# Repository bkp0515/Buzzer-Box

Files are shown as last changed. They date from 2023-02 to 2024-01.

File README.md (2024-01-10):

# Buzzer-Box
A project designed to create an alternative solution to existing buzzer systems for bible quizzing.

## Features
The hardware revision 2 contains new features like a larger buzzer with hardware controllable volume courtousy of a PAM8904.
Additionally, the faceplate has been redesigned to operate on i2c communication to be removable with just a single 5 pin JST connection.
Being based on the ESP32 feather V2 by adafruit, bluetooth and wifi features will be added eventually. 
Build guide and BOM to come after prototyping hardware V2 is more solidified.

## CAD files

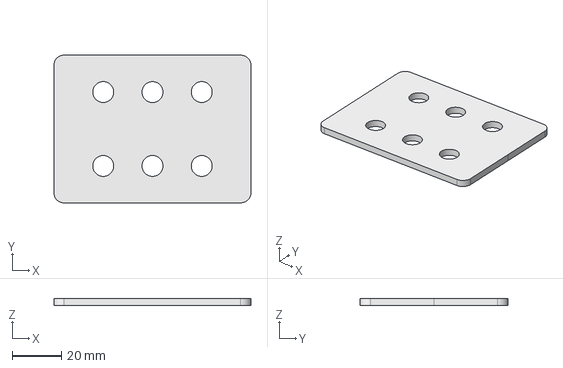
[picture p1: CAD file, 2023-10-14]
3dModels/QuizBoxMk2.FCStd
80.0 x 60.0 x 3.00 mm

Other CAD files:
3dModels/QuizBoxMk2-Sketch001.stl

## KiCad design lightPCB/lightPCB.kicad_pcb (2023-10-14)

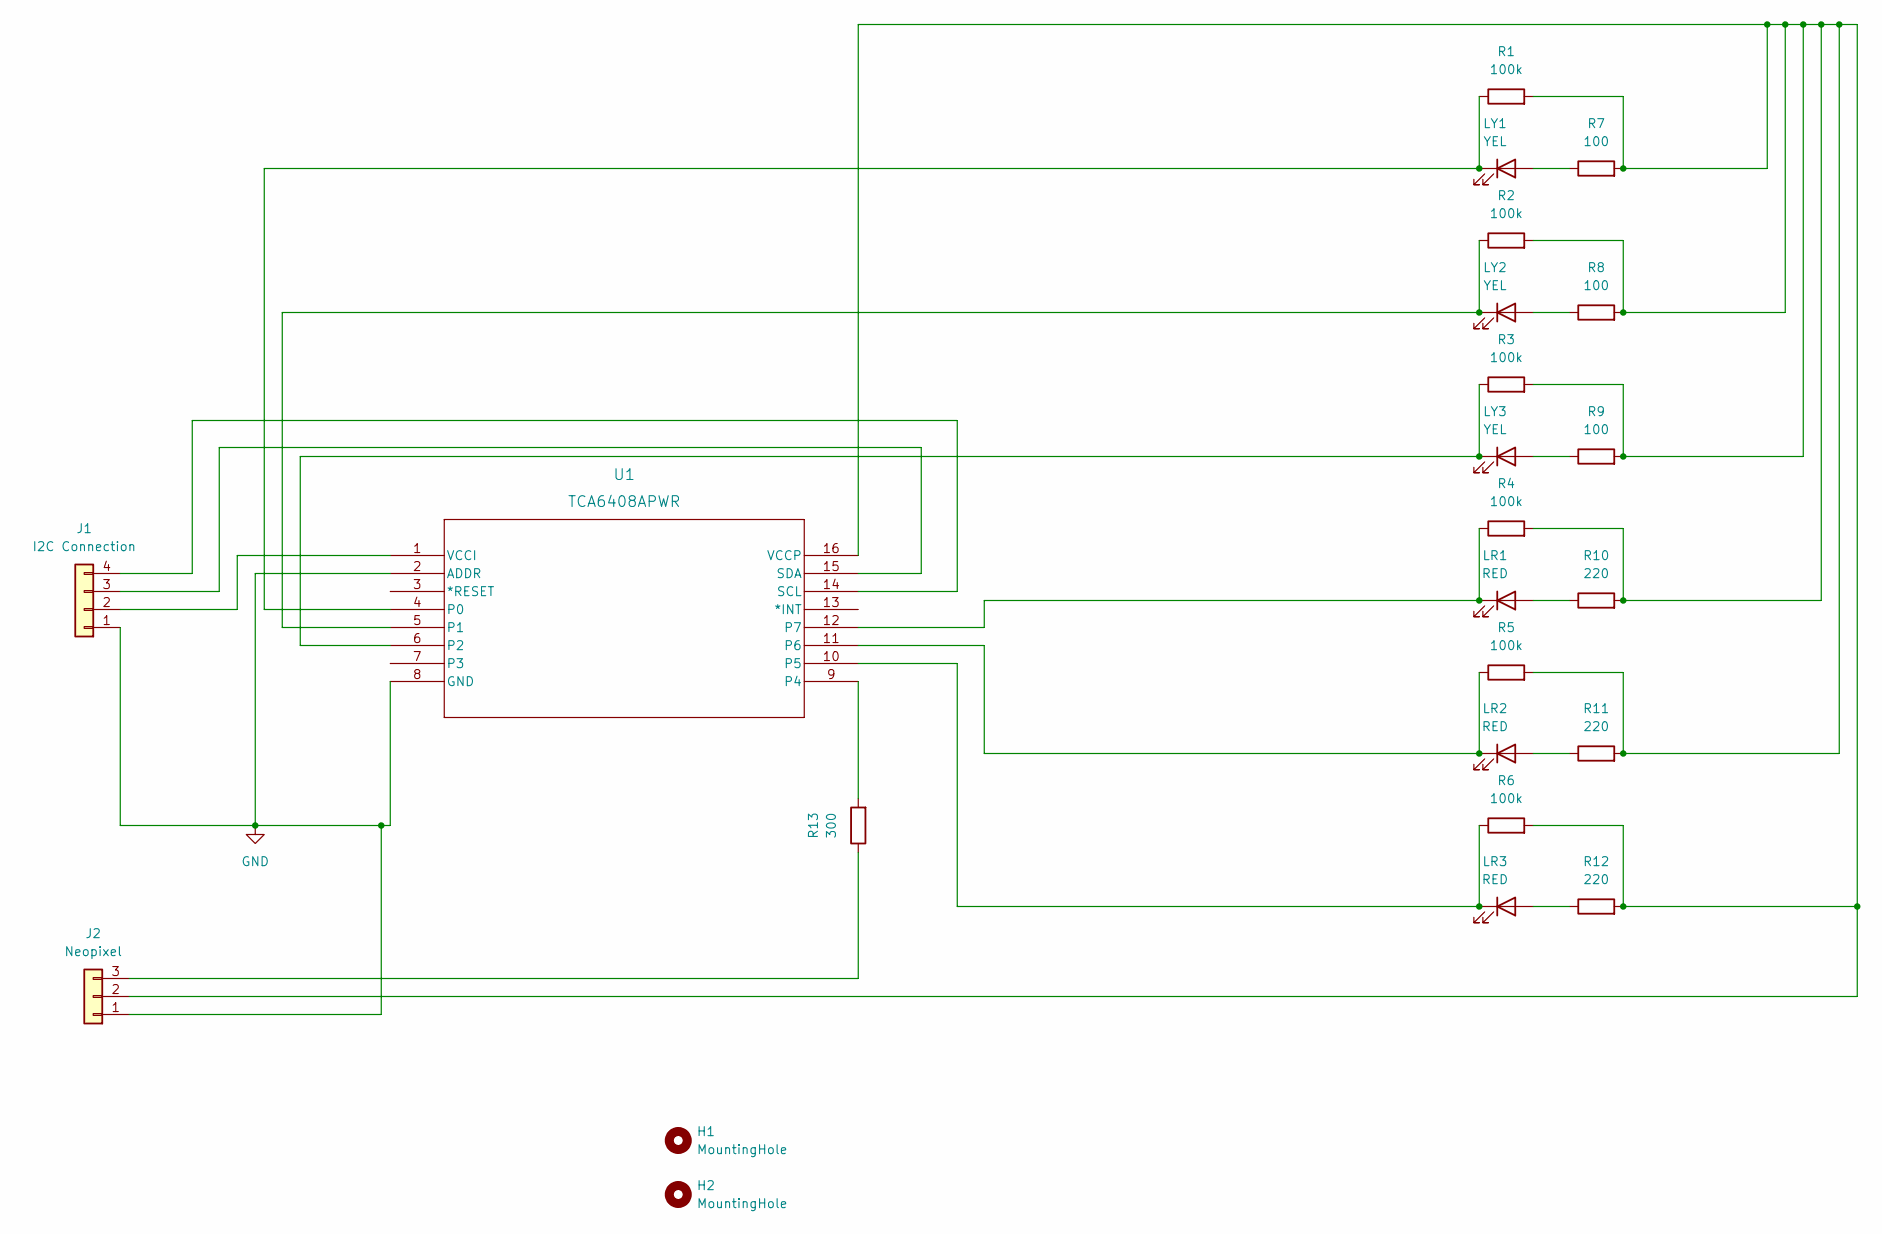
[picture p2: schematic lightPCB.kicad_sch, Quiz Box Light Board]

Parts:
H1, H2: MountingHole; MountingHole_2.2mm_M2_Pad
J1: I2C Connection; PinHeader_1x04_P2.54mm_Vertical
J2: Neopixel; PinHeader_1x03_P2.54mm_Vertical
LR1, LR2, LR3: RED; LED_D5.0mm
LY1, LY2, LY3: YEL; LED_D5.0mm
R1, R2, R3, R4, R5, R6: 100k; R_1206_3216Metric
R7, R8, R9: 100; R_1206_3216Metric
R10, R11, R12: 220; R_1206_3216Metric
R13: 300; R_1206_3216Metric
U1: TCA6408APWR; PW16

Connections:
GND: J1.1, J2.1, U1.2 (ADDR), U1.8 (GND)
unnamed: J1.2, U1.1 (VCCI)
unnamed: J2.3, R13.1
unnamed: LR1.2 (A), R10.1
unnamed: LR2.2 (A), R11.1
unnamed: LR3.2 (A), R12.1
unnamed: LY1.2 (A), R7.1
unnamed: LY2.2 (A), R8.1
unnamed: LY3.2 (A), R9.1
unnamed: LY1.1 (K), R1.1, U1.4 (P0)
unnamed: LY2.1 (K), R2.1, U1.5 (P1)
unnamed: LY3.1 (K), R3.1, U1.6 (P2)
unnamed: R13.2, U1.9 (P4)
unnamed: LR3.1 (K), R6.1, U1.10 (P5)
unnamed: LR2.1 (K), R5.1, U1.11 (P6)
unnamed: LR1.1 (K), R4.1, U1.12 (P7)
unnamed: J1.4, U1.14 (SCL)
unnamed: J1.3, U1.15 (SDA)
unnamed: J2.2, R1.2, R2.2, R3.2, R4.2, R5.2, R6.2, R7.2, R8.2, R9.2, R10.2, R11.2, R12.2, U1.16 (VCCP)

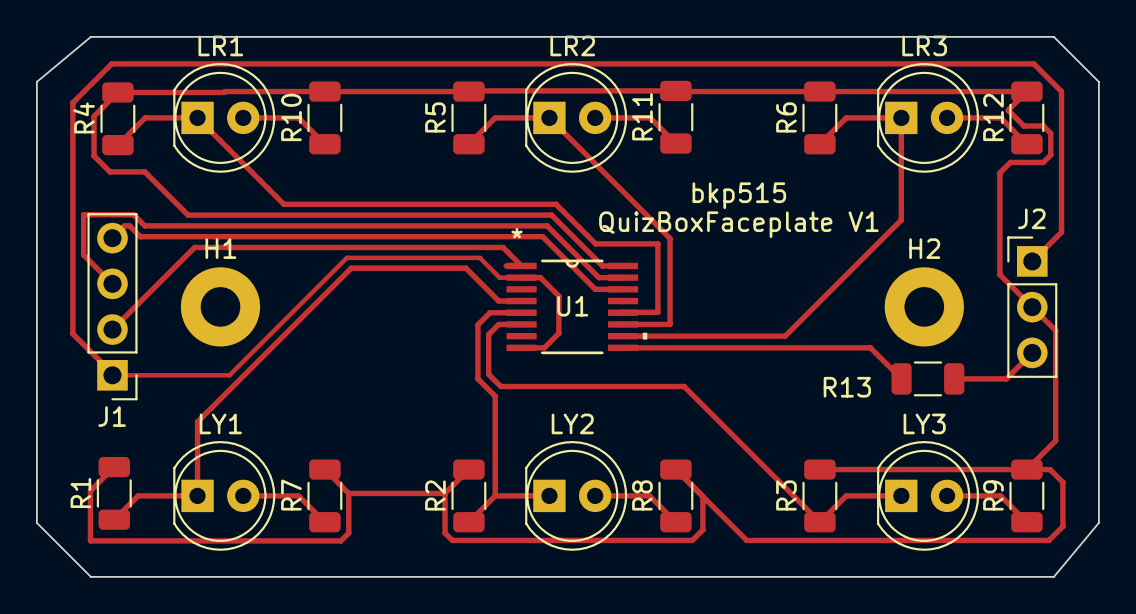
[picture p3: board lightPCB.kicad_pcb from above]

Board: 2 copper layers, 59.0 x 30.0 mm, 24 parts (0 on the bottom side), 19 nets.

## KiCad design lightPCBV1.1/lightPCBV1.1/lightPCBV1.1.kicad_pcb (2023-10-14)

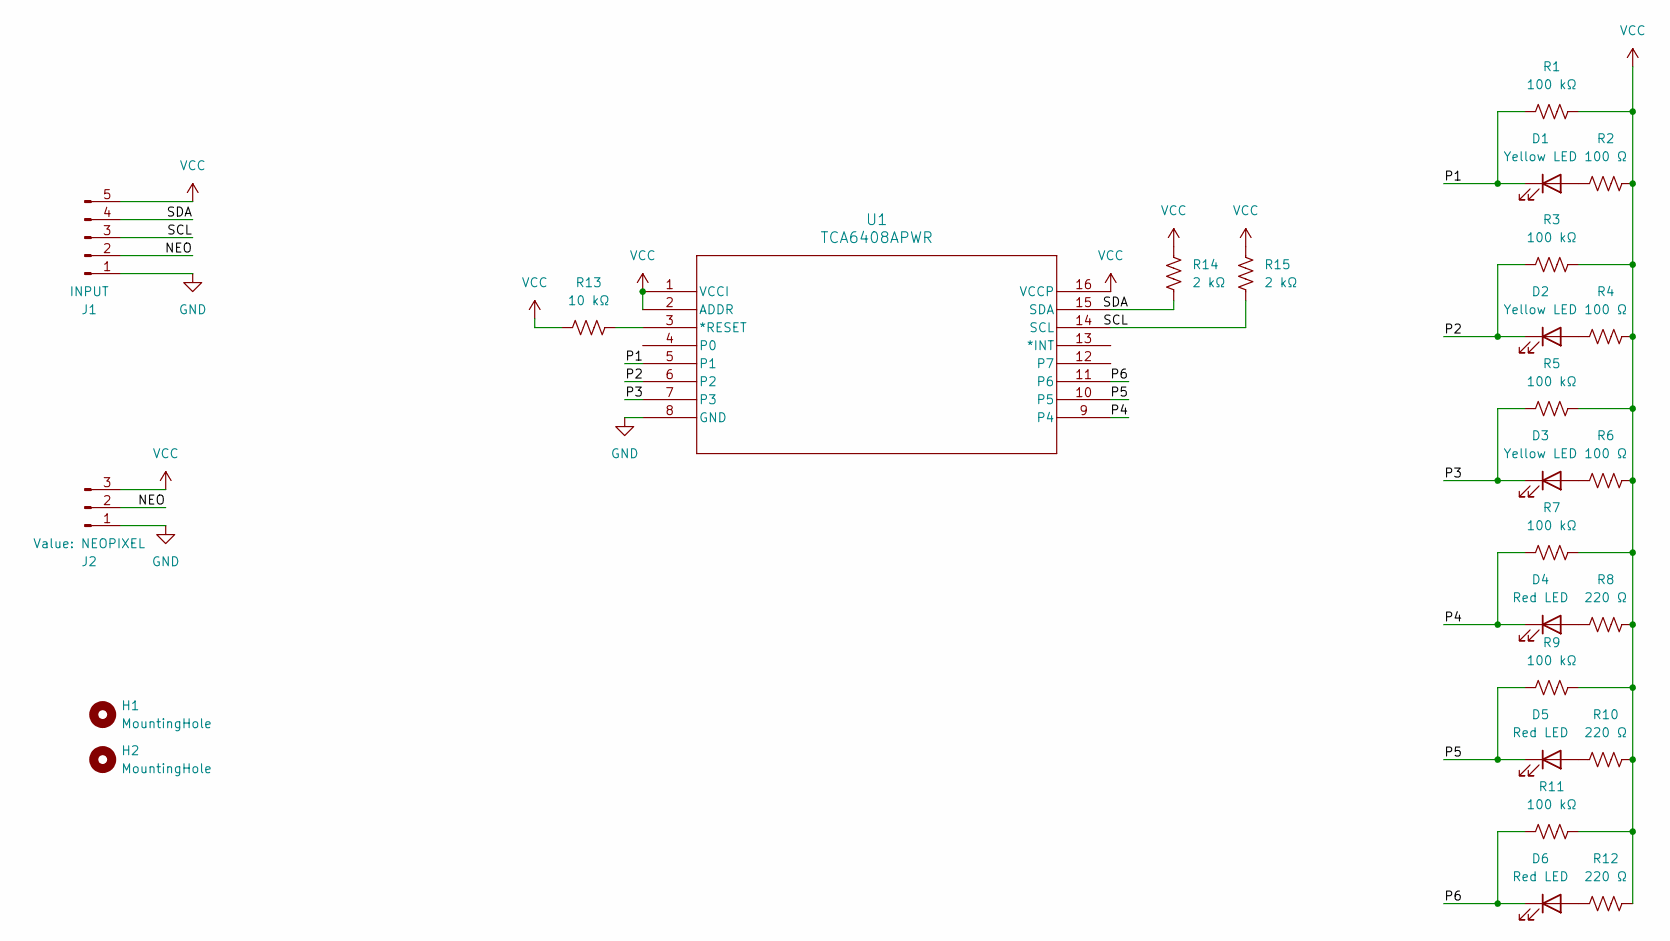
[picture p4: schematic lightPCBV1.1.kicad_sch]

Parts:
D1, D2, D3: Yellow LED; LED_D5.0mm
D4, D5, D6: Red LED; LED_D5.0mm
H1, H2: MountingHole; MountingHole_2.2mm_M2
J1: INPUT; JST_PH_B5B-PH-K_1x05_P2.00mm_Vertical
J2: NEOPIXEL; PinHeader_1x03_P2.54mm_Vertical
R1, R3, R5, R7, R9, R11: 100 kΩ; R_1206_3216Metric_Pad1.30x1.75mm_HandSolder
R2, R4, R6: 100 Ω; R_1206_3216Metric_Pad1.30x1.75mm_HandSolder
R8, R10, R12: 220 Ω; R_1206_3216Metric_Pad1.30x1.75mm_HandSolder
R13: 10 kΩ; R_1206_3216Metric_Pad1.30x1.75mm_HandSolder
R14, R15: 2 kΩ; R_1206_3216Metric_Pad1.30x1.75mm_HandSolder
U1: TCA6408APWR; PW16

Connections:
/NEO: J1.2, J2.2
/P1: D1.1 (K), R1.1, U1.5 (P1)
/P2: D2.1 (K), R3.1, U1.6 (P2)
/P3: D3.1 (K), R5.1, U1.7 (P3)
/P4: D4.1 (K), R7.1, U1.9 (P4)
/P5: D5.1 (K), R9.1, U1.10 (P5)
/P6: D6.1 (K), R11.1, U1.11 (P6)
/SCL: J1.3, R15.2, U1.14 (SCL)
/SDA: J1.4, R14.1, U1.15 (SDA)
GND: J1.1, J2.1, U1.8 (GND)
unnamed: D1.2 (A), R2.1
unnamed: D2.2 (A), R4.1
unnamed: D3.2 (A), R6.1
unnamed: D4.2 (A), R8.1
unnamed: D5.2 (A), R10.1
unnamed: D6.2 (A), R12.1
unnamed: R13.2, U1.3 (*RESET)
VCC: J1.5, J2.3, R1.2, R2.2, R3.2, R4.2, R5.2, R6.2, R7.2, R8.2, R9.2, R10.2, R11.2, R12.2, R13.1, R14.2, R15.1, U1.1 (VCCI), U1.2 (ADDR), U1.16 (VCCP)

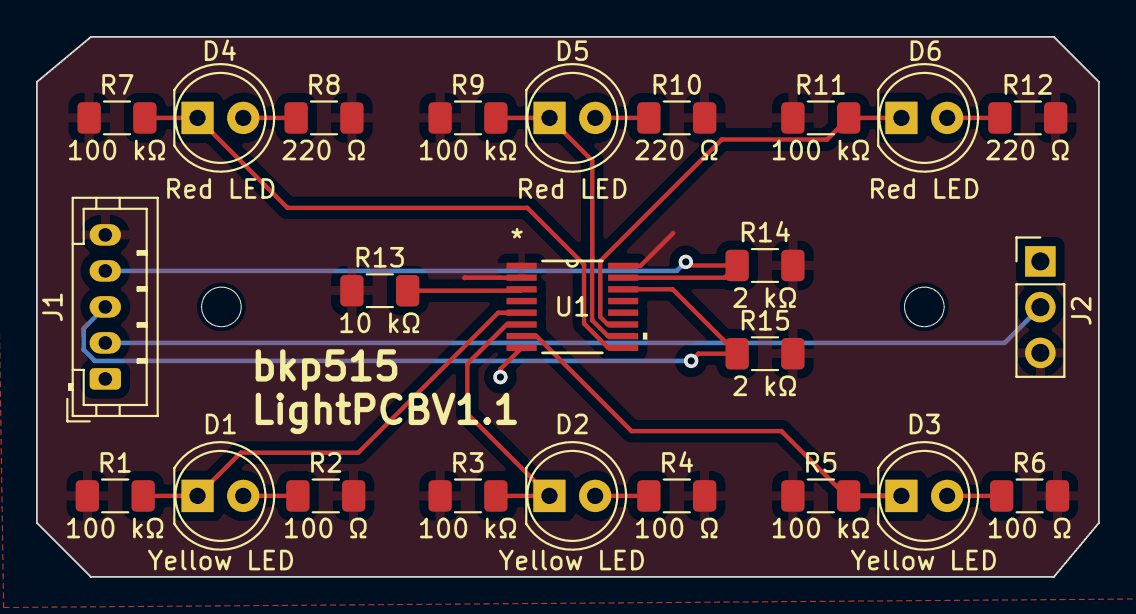
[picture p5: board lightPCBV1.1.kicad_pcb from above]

Board: 2 copper layers, 59.0 x 30.0 mm, 26 parts (0 on the bottom side), 18 nets.

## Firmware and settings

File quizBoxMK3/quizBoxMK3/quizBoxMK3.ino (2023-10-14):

// Quiz Box Mk. 3 Ben Pacheco 2/16/23
// Updated 2/21/23
////////////////////////////////////////////////////////////////////////////////////////////
// Library includes
#include <Adafruit_NeoPixel.h>
#include "driver/rtc_io.h"
#include <FastLED.h>
#ifdef __AVR__
#include <avr/power.h>
#endif

////////////////////////////////////////////////////////////////////////////////////////////
// Sleep function setup stuff
////////////////////////////////////////////////////////////////////////////////////////////

#define BUTTON_PIN_BITMASK 0x004000000 // 2^26 in hex define power switch pin
#define ps    26 // Power switch pin define

////////////////////////////////////////////////////////////////////////////////////////////
// End sleep function stuff
////////////////////////////////////////////////////////////////////////////////////////////


////////////////////////////////////////////////////////////////////////////////////////////
// Neopixel Setup Stuff
////////////////////////////////////////////////////////////////////////////////////////////

#define DATA_PIN    19 //Set pin for neopixels
#define NUM_LEDS    8  //Set number of neopixels

// Input the neopixel variables
CRGB leds[NUM_LEDS];
//Adafruit_NeoPixel pixels(NUMPIXELS, neoPIN, NEO_GRB + NEO_KHZ800);

////////////////////////////////////////////////////////////////////////////////////////////
// End Neopixel Setup
////////////////////////////////////////////////////////////////////////////////////////////


////////////////////////////////////////////////////////////////////////////////////////////
// Timer Setup
////////////////////////////////////////////////////////////////////////////////////////////
// Timer variables
volatile uint8_t isrCounter = 0;
volatile bool timerOn = false;
uint8_t pixelsOn = 0;

// Setup timer
hw_timer_t * timer = NULL;
hw_timer_t * speedTimer = NULL;
hw_timer_t * buzzTimer = NULL;

////////////////////////////////////////////////////////////////////////////////////////////
// End timer setup
////////////////////////////////////////////////////////////////////////////////////////////

// Define pins
#define b1    13 // Buzzer 1 (passive buzzer)
#define b2    12 // Buzzer 2 (active buzzer)
#define r1p   14 // Red 1 buzzer pin
#define r2p   15 // Red 2 buzzer pin
#define r3p   27 // Red 3 buzzer pin
#define y1p   4  // Yellow 1 buzzer pin
#define y2p   8  // Yellow 2 buzzer pin
#define y3p   36 // Yellow 3 buzzer pin
#define rp    22 // Reader pin

#define r1l   33 //Red 1 LED
#define r2l   32 //Red 2 LED
#define r3l   20 //Red 3 LED
#define y1l   21 //Yellow 1 LED
#define y2l   7  //Yellow 2 LED
#define y3l   5  //Yellow 3 LED


// Buzzer definition 
struct Buzzer {
  const uint8_t PIN; // 
  volatile uint64_t SPEED;
  bool pressed;
};

// Define buzzers
Buzzer handle1 = {r1p, 0, false};
Buzzer handle2 = {r2p, 0, false};
Buzzer handle3 = {r3p, 0, false};
Buzzer handle4 = {y1p, 0, false};
Buzzer handle5 = {y2p, 0, false};
Buzzer handle6 = {y3p, 0, false};
Buzzer handle7 = {rp , 0, false};

// Buzzer interrupt variables
volatile bool buzzed = false;
volatile uint8_t first = 0;

////////////////////////////////////////////////////////////////////////////////////////////
// Buzzer Interrupts
////////////////////////////////////////////////////////////////////////////////////////////
void ARDUINO_ISR_ATTR isrH1() { // Red 1
  if (!buzzed) {
    handle1.pressed = true;
    buzzed = true;
    first = 1;
    timerWrite(speedTimer, 0);
    timerStart(speedTimer);
  } else {
    handle1.SPEED = timerRead(speedTimer);
  }
}


void ARDUINO_ISR_ATTR isrH2() { // Red 2
  if (!buzzed) {
    handle2.pressed = true;
    buzzed = true;
    first = 2;
    timerWrite(speedTimer, 0);
    timerStart(speedTimer);
  } else {
    handle2.SPEED = timerRead(speedTimer);
  }
}

void ARDUINO_ISR_ATTR isrH3() { // Red 3
  if (!buzzed) {
    handle3.pressed = true;
    buzzed = true;
    first = 3;
    timerWrite(speedTimer, 0);
    timerStart(speedTimer);
  } else {
    handle3.SPEED = timerRead(speedTimer);
  }
}

void ARDUINO_ISR_ATTR isrH4() { // Yellow 1
  if (!buzzed) {
    handle4.pressed = true;
    buzzed = true;
    first = 4;
    timerWrite(speedTimer, 0);
    timerStart(speedTimer);
  } else {
    handle4.SPEED = timerRead(speedTimer);
  }
}

void ARDUINO_ISR_ATTR isrH5() { // Yellow 2
  if (!buzzed) {
    handle5.pressed = true;
    buzzed = true;
    first = 5;
    timerWrite(speedTimer, 0);
    timerStart(speedTimer);
  } else {
    handle5.SPEED = timerRead(speedTimer);
  }
}

void ARDUINO_ISR_ATTR isrH6() { // Yellow 3
  if (!buzzed) {
    handle6.pressed = true;
    buzzed = true;
    first = 6;
    timerWrite(speedTimer, 0);
    timerStart(speedTimer);
  } else {
    handle6.SPEED = timerRead(speedTimer);
  }
}

void ARDUINO_ISR_ATTR isrH7() { // Clear Handle
  if (!buzzed) {
    first = 7;
    
    
  } else {
    isrCounter = 0;
    timerStop(timer);
  }
}
////////////////////////////////////////////////////////////////////////////////////////
// Speed timer reset
////////////////////////////////////////////////////////////////////////////////////////

void ARDUINO_ISR_ATTR speedTimerInt() {
  timerStop(speedTimer); // Stop the speed timer upon interrupt
}


void ARDUINO_ISR_ATTR buzzTimerInt() {
  digitalWrite(b2, LOW);
  timerStop(buzzTimer);
  //buzzing = false;
}
////////////////////////////////////////////////////////////////////////////////////////////
// Timer Function Stuff
////////////////////////////////////////////////////////////////////////////////////////////

// Timer interrupt function
void ARDUINO_ISR_ATTR onTimer() {
  if (isrCounter > 0) { // Check the number of times the ISR has been called

    isrCounter--;
  }
}

// Start timer function
void startTimer(uint8_t timeLenght, uint8_t R, uint8_t G, uint8_t B) { // Call to start a timer
  if (timerOn == false){ // Check if a timer is already started
    
    // Set all the pixels to the defined color
    for(int j = 0; j<NUM_LEDS; j++){ 
      leds[j].setRGB( R, G, B);
      FastLED.show();
    } // End for

    // Configure timer
    timerOn = true; // Set flag to show a timer is running
    timerAlarmWrite(timer, (timeLenght * 1000000 / NUM_LEDS), true); // Set the interrupt lenght of the timer
    timerRestart(timer); // Start the timer from 0
    timerStart(timer);
    timerAlarmEnable(timer); // Allow timer interupt
    isrCounter = NUM_LEDS; // Set the counter to the number of pixels to begin countdown
    pixelsOn = NUM_LEDS; // Set the number of pixels currently on
    
  } // end if
  
} // end function

///////////////////////////////////////////////////////////////////////////////////////////
// End Timer Function Stuff
///////////////////////////////////////////////////////////////////////////////////////////

////////////////////////////////////////////////////////////////////////////////////////
// Main Setup and Script
////////////////////////////////////////////////////////////////////////////////////////

void setup() {
  // Configure power switch
  rtc_gpio_pullup_dis(GPIO_NUM_26);
  rtc_gpio_pulldown_en(GPIO_NUM_26);
  esp_sleep_enable_ext0_wakeup(GPIO_NUM_26,1);
  
  // Start the neopixels
  //pixels.begin();
  FastLED.addLeds<NEOPIXEL, DATA_PIN>(leds, NUM_LEDS);
  // initialize buttons
  pinMode(r1p, INPUT_PULLUP);
  pinMode(r2p, INPUT_PULLUP);
  pinMode(r3p, INPUT_PULLUP);
  pinMode(y1p, INPUT_PULLUP);
  pinMode(y2p, INPUT_PULLUP);
  pinMode(y3p, INPUT_PULLUP);
  pinMode(rp,  INPUT_PULLUP);
  // Initalize LEDs
  pinMode(y1l, OUTPUT);
  pinMode(y2l, OUTPUT);
  pinMode(y3l, OUTPUT);
  pinMode(r1l, OUTPUT);
  pinMode(r2l, OUTPUT);
  pinMode(r3l, OUTPUT);
  pinMode(b2,  OUTPUT);

  // Connect interrupts to buzzers
  attachInterrupt(handle1.PIN, isrH1, FALLING);
  attachInterrupt(handle2.PIN, isrH2, FALLING);
  attachInterrupt(handle3.PIN, isrH3, FALLING);
  attachInterrupt(handle4.PIN, isrH4, FALLING);
  attachInterrupt(handle5.PIN, isrH5, FALLING);
  attachInterrupt(handle6.PIN, isrH6, FALLING);
  attachInterrupt(handle7.PIN, isrH7, FALLING);
  
  
  // Play tone to indicate power on
  tone(b1, 1500, 500);
  // Clear the neopixels
  //pixels.clear();
  //pixels.show();
  
  // Initialize timer 0, 1 and 2 with an 80 prescaler and define autoreload
  timer = timerBegin(0, 80, true);
  speedTimer = timerBegin(1, 80, true);
  buzzTimer = timerBegin(2, 80, true);
  
  // Attach the interrupt function to the timer
  timerAttachInterrupt(timer, &onTimer, true);
  timerAttachInterrupt(speedTimer, &speedTimerInt, true);
  timerAttachInterrupt(buzzTimer, &buzzTimerInt, true);

  
  
  
  timerAlarmWrite(buzzTimer, 500000, false); // Set the buzzer timer limit
  timerAlarmWrite(speedTimer, 5000000, false); // Set the speed timer limit
  
  
  //startTimer(5, pixels.Color(25, 25, 25));
}

void loop() {
  if (buzzed) {
    buzz(first);
  }
  
}

////////////////////////////////////////////////////////////////////////////////////////////
// End Main Setup and Script
////////////////////////////////////////////////////////////////////////////////////////////


////////////////////////////////////////////////////////////////////////////////////////////
// Buzz function
////////////////////////////////////////////////////////////////////////////////////////////

void buzz(uint8_t x) {
  switch(x) {
    case 1 :
      // Red one
      if (!timerOn){
        startTimer(30, 25, 0, 0);// Start the 30 seccond countdown
        
        timerRestart(buzzTimer); // Set the buzzer timer to 0
        timerStart(buzzTimer); // Make sure the buzzer timer is started
        timerAlarmEnable(buzzTimer); // Run the buzzer timer to the alarm
        digitalWrite(b2, HIGH); // Turn on the buzzer
        digitalWrite(r1l, HIGH); // Turn on the red 1 light
      } else { 
        if (pixelsOn > isrCounter) { // Check if pixel needs to be turned off
          pixelsOn--;
          leds[pixelsOn].setRGB( 0, 0, 0);
          FastLED.show();
        } else if (pixelsOn == 0){ // After all the pixels are off (Times up)
          
          timerOn = false; // Timer is no longer running
          timerStop(timer); // disable timer
          tone(b1, 500, 500); // Indicate time
          digitalWrite(r1l, LOW);
          buzzed = false; // Exit buzzed state
        }
      }
    case 2 :
      // Red two
      if (!timerOn){
        startTimer(30, 25, 0, 0);// Start the 30 seccond countdown
        
        timerRestart(buzzTimer); // Set the buzzer timer to 0
        timerStart(buzzTimer); // Make sure the buzzer timer is started
        timerAlarmEnable(buzzTimer); // Run the buzzer timer to the alarm
        digitalWrite(b2, HIGH); // Turn on the buzzer
        digitalWrite(r2l, HIGH); // Turn on the red 1 light
      } else { 
        if (pixelsOn > isrCounter) { // Check if pixel needs to be turned off
          pixelsOn--;
          leds[pixelsOn].setRGB( 0, 0, 0);
          FastLED.show();
        } else if (pixelsOn == 0){ // After all the pixels are off (Times up)
          
          timerOn = false; // Timer is no longer running
          timerStop(timer); // disable timer
          tone(b1, 500, 500); // Indicate time
          digitalWrite(r2l, LOW);
          buzzed = false; // Exit buzzed state
        }
      }
    case 3 :
      // Red three
      if (!timerOn){
        startTimer(30, 25, 0, 0);// Start the 30 seccond countdown
        
        timerRestart(buzzTimer); // Set the buzzer timer to 0
        timerStart(buzzTimer); // Make sure the buzzer timer is started
        timerAlarmEnable(buzzTimer); // Run the buzzer timer to the alarm
        digitalWrite(b2, HIGH); // Turn on the buzzer
        digitalWrite(r3l, HIGH); // Turn on the red 1 light
      } else { 
        if (pixelsOn > isrCounter) { // Check if pixel needs to be turned off
          pixelsOn--;
          leds[pixelsOn].setRGB( 0, 0, 0);
          FastLED.show();
        } else if (pixelsOn == 0){ // After all the pixels are off (Times up)
          
          timerOn = false; // Timer is no longer running
          timerStop(timer); // disable timer
          tone(b1, 500, 500); // Indicate time
          digitalWrite(r3l, LOW);
          buzzed = false; // Exit buzzed state
        }
      }
    case 4 :
      // Yellow one
      if (!timerOn){
        startTimer(30, 25, 25, 0);// Start the 30 seccond countdown
        
        timerRestart(buzzTimer); // Set the buzzer timer to 0
        timerStart(buzzTimer); // Make sure the buzzer timer is started
        timerAlarmEnable(buzzTimer); // Run the buzzer timer to the alarm
        digitalWrite(b2, HIGH); // Turn on the buzzer
        digitalWrite(y1l, HIGH); // Turn on the red 1 light
      } else { 
        if (pixelsOn > isrCounter) { // Check if pixel needs to be turned off
          pixelsOn--;
          leds[pixelsOn].setRGB( 0, 0, 0);
          FastLED.show();
        } else if (pixelsOn == 0){ // After all the pixels are off (Times up)
          
          timerOn = false; // Timer is no longer running
          timerStop(timer); // disable timer
          tone(b1, 500, 500); // Indicate time
          digitalWrite(y1l, LOW);
          buzzed = false; // Exit buzzed state
        }
      }
    case 5 :
      // Yellow Two
      if (!timerOn){
        startTimer(30, 25, 25, 0);// Start the 30 seccond countdown
        
        timerRestart(buzzTimer); // Set the buzzer timer to 0
        timerStart(buzzTimer); // Make sure the buzzer timer is started
        timerAlarmEnable(buzzTimer); // Run the buzzer timer to the alarm
        digitalWrite(b2, HIGH); // Turn on the buzzer
        digitalWrite(y2l, HIGH); // Turn on the red 1 light
      } else { 
        if (pixelsOn > isrCounter) { // Check if pixel needs to be turned off
          pixelsOn--;
          leds[pixelsOn].setRGB( 0, 0, 0);
          FastLED.show();
        } else if (pixelsOn == 0){ // After all the pixels are off (Times up)
          
          timerOn = false; // Timer is no longer running
          timerStop(timer); // disable timer
          tone(b1, 500, 500); // Indicate time
          digitalWrite(y2l, LOW);
          buzzed = false; // Exit buzzed state
        }
      }
    case 6 :
      // Yellow Two
      if (!timerOn){
        startTimer(30, 25, 25, 0);// Start the 30 seccond countdown
        
        timerRestart(buzzTimer); // Set the buzzer timer to 0
        timerStart(buzzTimer); // Make sure the buzzer timer is started
        timerAlarmEnable(buzzTimer); // Run the buzzer timer to the alarm
        digitalWrite(b2, HIGH); // Turn on the buzzer
        digitalWrite(y3l, HIGH); // Turn on the red 1 light
      } else { 
        if (pixelsOn > isrCounter) { // Check if pixel needs to be turned off
          pixelsOn--;
          leds[pixelsOn].setRGB( 0, 0, 0);
          FastLED.show();
        } else if (pixelsOn == 0){ // After all the pixels are off (Times up)
          
          timerOn = false; // Timer is no longer running
          timerStop(timer); // disable timer
          tone(b1, 500, 500); // Indicate time
          digitalWrite(y3l, LOW);
          buzzed = false; // Exit buzzed state
        }
      }
  }
}

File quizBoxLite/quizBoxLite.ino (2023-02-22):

// QuizBox Lite. Ben Pacheco 7/29/22
// Updated 1/21/23 by Ben Pacheco
// Setup neopixel strip
#include <Adafruit_NeoPixel.h>
#include "driver/rtc_io.h"
#ifdef __AVR__
  #include <avr/power.h>
#endif

// Set sleep wake button
#define BUTTON_PIN_BITMASK 0x004000000 // 2^26 in hex

// Setup pins for neopixels
#define neoPIN       19
#define NUMPIXELS 8

// Input the neopixel variables
Adafruit_NeoPixel pixels(NUMPIXELS, neoPIN, NEO_GRB + NEO_KHZ800);

// Set pins
const int b1 = 13;
const int b2 = 12;
const int r1b = 27;
const int r2b = 15;
const int r3b = 14;
const int y1b = 36;
const int y2b = 8;
const int y3b = 4;
const int rb = 22;
const int ps = 26;

// Create variable for switches
int r1s = 0;
int r2s = 0;
int r3s = 0;
int y1s = 0;
int y2s = 0;
int y3s = 0;
int rs = 0;
int pss = 0;
// Create a structure for the clear handle. Stores info like what pin its on.
struct clr {
  const uint8_t clearPin; // Create a variable for the pin
  bool pressed; // Create a boolian to store weather the button is pressed.
};

clr clr1 = {22, false}; // Create the reader handle object

void IRAM_ATTR isr() { // Function for clearing the buzzer
  pixels.clear(); // Clear the pixels
  pixels.show();
}

void setup() {
  // Configure power switch
  rtc_gpio_pullup_dis(GPIO_NUM_26);
  rtc_gpio_pulldown_en(GPIO_NUM_26);
  esp_sleep_enable_ext0_wakeup(GPIO_NUM_26,1);
  // Start the neopixels
  pixels.begin();
  pixels.show();
  // initialize buttons
  pinMode(r1b, INPUT_PULLUP);
  pinMode(r2b, INPUT_PULLUP);
  pinMode(r3b, INPUT_PULLUP);
  pinMode(y1b, INPUT_PULLUP);
  pinMode(y2b, INPUT_PULLUP);
  pinMode(y3b, INPUT_PULLUP);
  pinMode(rb, INPUT_PULLUP);
  pinMode(ps, INPUT);
  // Play tone to indicate power on
  tone(b1, 1000);
  tone(b2, 1500);
  delay(500);
  noTone(b1);
  noTone(b2);
  // Connect the interrupt to the isr function
  attachInterrupt(clr1.clearPin, isr, FALLING);
  
}

void loop() {
  // Clear neopixels
  pixels.clear();
  pixels.show();
  // Read all the handels
  r1s = digitalRead(r1b);
  r2s = digitalRead(r2b);
  r3s = digitalRead(r3b);
  y1s = digitalRead(y1b);
  y2s = digitalRead(y2b);
  y3s = digitalRead(y3b);
  rs = digitalRead(rb);
  pss = digitalRead(ps);
  // If statement to check the buzzer states
  if (pss == LOW){
    esp_deep_sleep_start(); // Put the microcontroller to sleep

  } else if (r2s == LOW){
    buzz(2);
  } else if (r3s == LOW){
    buzz(3);
  } else if (y1s == LOW){
    buzz(4);
  } else if (y2s == LOW){
    buzz(5);
  } else if (y3s == LOW){
    buzz(6);
  } else if (r1s == LOW){
    buzz(1); // Call buzz function
  }
}



void buzz(int x) {
  switch(x) {
    case 1 :
      // Red one
      pixels.clear(); // Clear any outstanding colors
      pixels.setPixelColor(0, pixels.Color(50, 0, 0)); // Set the first two leds red
      pixels.setPixelColor(1, pixels.Color(50, 0, 0));
      pixels.show(); // Display the pixels
      
      //tone(b1, 300); // Buzz
      digitalWrite(b2, HIGH);
      delay(500);
      digitalWrite(b2, LOW);
      //noTone(b1); // Stop Buzz
      delay(30000); // Thirty seccond timer
      tone(b1, 500, 100); // Indicate time
      delay(100);
      tone(b1, 500, 100);
      pixels.clear(); // Clear pixels
      pixels.show();
      break;
    case 2 :
      // Red two
      pixels.clear();
      pixels.setPixelColor(0, pixels.Color(50, 0, 0)); // Set the first two leds red
      pixels.setPixelColor(1, pixels.Color(50, 0, 0));
      pixels.setPixelColor(3, pixels.Color(50, 0, 0)); // Set the third and fourth leds red
      pixels.setPixelColor(4, pixels.Color(50, 0, 0));      
      pixels.show(); // Display the pixels

      tone(b1, 300); // Buzz
      delay(500);
      noTone(b1); // Stop Buzz
      delay(30000); // Thirty seccond timer
      tone(b1, 500, 100); // Indicate time
      delay(100);
      tone(b1, 500, 100);
      pixels.clear(); // Clear pixels
      pixels.show();
      break;
    case 3 :
      // Red three
      pixels.clear();
      pixels.setPixelColor(0, pixels.Color(50, 0, 0)); // Set the first two leds red
      pixels.setPixelColor(1, pixels.Color(50, 0, 0));
      pixels.setPixelColor(3, pixels.Color(50, 0, 0)); // Set the third and fourth leds red
      pixels.setPixelColor(4, pixels.Color(50, 0, 0));
      pixels.setPixelColor(6, pixels.Color(50, 0, 0)); // Set the sixth and seventh leds red
      pixels.setPixelColor(7, pixels.Color(50, 0, 0));             
      pixels.show(); // Display the pixels

      tone(b1, 300); // Buzz
      delay(500);
      noTone(b1); // Stop Buzz
      delay(30000); // Thirty seccond timer
      tone(b1, 500, 100); // Indicate time
      delay(100);
      tone(b1, 500, 100);
      pixels.clear(); // Clear pixels
      pixels.show();
      break;
    case 4 :
      // Yellow one
      pixels.clear(); // Clear any outstanding colors
      pixels.setPixelColor(0, pixels.Color(50, 50, 0)); // Set the first two leds yellow
      pixels.setPixelColor(1, pixels.Color(50, 50, 0));
      pixels.show(); // Display the pixels
      
      tone(b1, 300); // Buzz!
      delay(500);
      noTone(b1); // Stop buzz
      delay(30000); // Thirty seccond timer
      tone(b1, 500, 100); // Indicate time
      delay(100);
      tone(b1, 500, 100);
      pixels.clear(); // Clear pixels
      pixels.show();
      break;
    case 5 :
      // Yellow two
      pixels.clear();
      pixels.setPixelColor(0, pixels.Color(50, 50, 0)); // Set the first two leds yellow
      pixels.setPixelColor(1, pixels.Color(50, 50, 0));
      pixels.setPixelColor(3, pixels.Color(50, 50, 0)); // Set the third and fourth leds yellow
      pixels.setPixelColor(4, pixels.Color(50, 50, 0));      
      pixels.show(); // Display the pixels

      tone(b1, 300); // Buzz
      delay(500);
      noTone(b1); // Stop Buzz
      delay(30000); // Thirty Seccond timer
      tone(b1, 500, 100); // Indicate time
      delay(100);
      tone(b1, 500, 100);
      pixels.clear(); // Clear pixels
      pixels.show();
      break;
    case 6 :
      //Yellow Three
      pixels.clear();
      pixels.setPixelColor(0, pixels.Color(50, 50, 0)); // Set the first two leds yellow
      pixels.setPixelColor(1, pixels.Color(50, 50, 0));
      pixels.setPixelColor(3, pixels.Color(50, 50, 0)); // Set the third and fourth leds yellow
      pixels.setPixelColor(4, pixels.Color(50, 50, 0));
      pixels.setPixelColor(6, pixels.Color(50, 50, 0)); // Set the sixth and seventh leds yellow
      pixels.setPixelColor(7, pixels.Color(50, 50, 0));             
      pixels.show(); // Display the pixels

      tone(b1, 300); // Buzz
      delay(500);
      noTone(b1); // Stop Buzz
      delay(30000); // Thirty seccond timer
      tone(b1, 500, 100); // Indicate time
      delay(100);
      tone(b1, 500, 100);
      pixels.clear(); // Clear pixels
      pixels.show();
      break;
    exit;
  }
   
}

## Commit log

2023-02-22 Created interrupts for new interrupt system of buzzing Created a function for red 1 to buzz adjusted timer function to fix non reloading
    [quizBoxMK3.ino]
2023-02-22 fixed timer not restarting after first buzz
    [quizBoxMK3.ino]
2023-02-22 Added buzzer timer and actual buzzing to red 1 buzz in function
    [quizBoxMK3.ino]
2023-02-22 Duplicated the buzz functino for the other buzzers, started causing problems exiting the buzz function
    [quizBoxMK3.ino]
2023-03-12 Replaced adafruit neopixel library with the fast led library to improve interrupt performace. Still having buzzes after timer runs out.
    [lightPCB-B_Cu.gbr, lightPCB-B_Mask.gbr, lightPCB-B_Paste.gbr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]
2023-08-04 Started work on a new PCB for the jacks to reduce hand wiring
    [jackPCB.kicad_pcb, jackPCB.kicad_sch, tca6408aBreakout.kicad_pcb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]
2023-10-14 Designed a new faceplace pcb and created a new test program to interface with the tca ic
    [QuizBoxMk2-Sketch001.stl, QuizBoxMk2.FCStd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]
